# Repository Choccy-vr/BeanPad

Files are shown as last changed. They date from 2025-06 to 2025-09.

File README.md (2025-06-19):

# BeanPad

A modular magnetic macro pad. Use many different modules to make the macro pad of your dreams. Modify the macros.json for a custom keymap.

I built this originally as a buffer for my main project but it has since taken over it. The idea came from other snap-fit modular systems and thought it was cool. I originally was just going to make a hack pad but it quickly grew into this.
I also built this in case my other project doesn't get finished in time for undercity.
## Images

### PCB

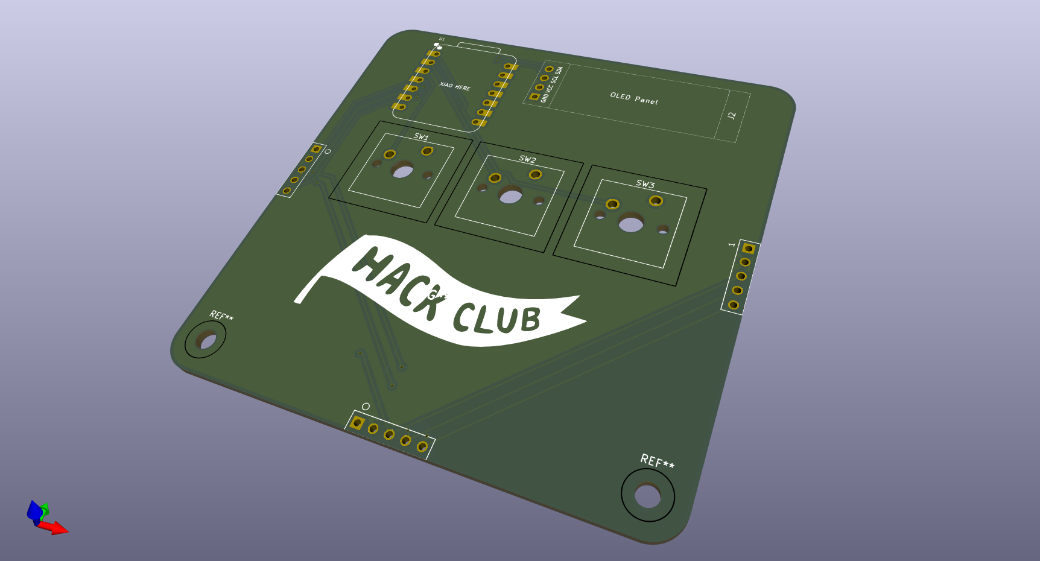
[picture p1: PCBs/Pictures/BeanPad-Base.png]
Screenshot 2025-06-09 151724.png


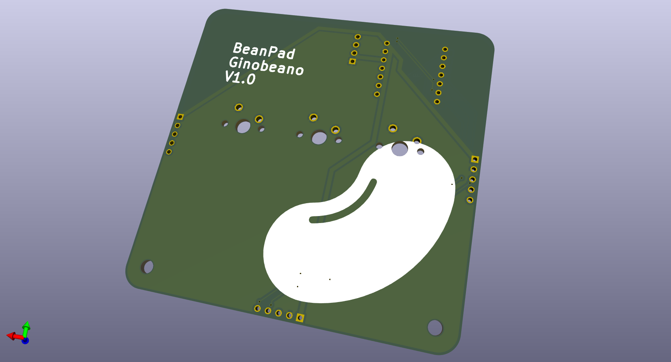
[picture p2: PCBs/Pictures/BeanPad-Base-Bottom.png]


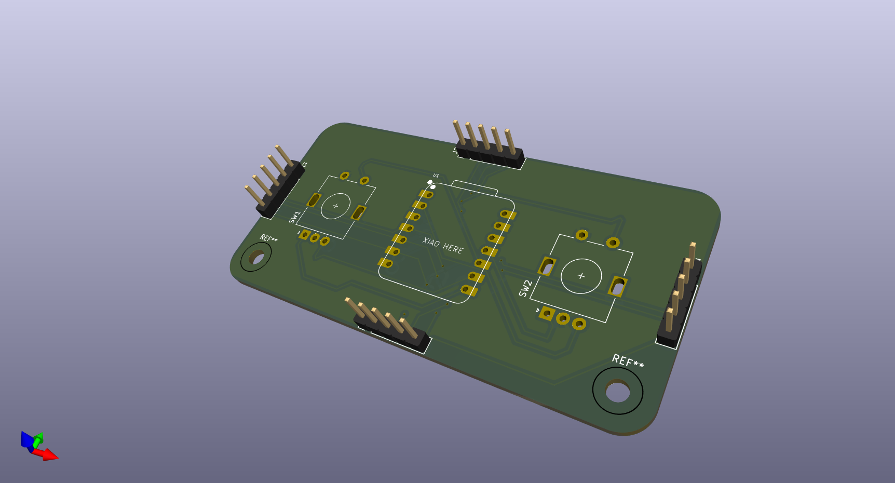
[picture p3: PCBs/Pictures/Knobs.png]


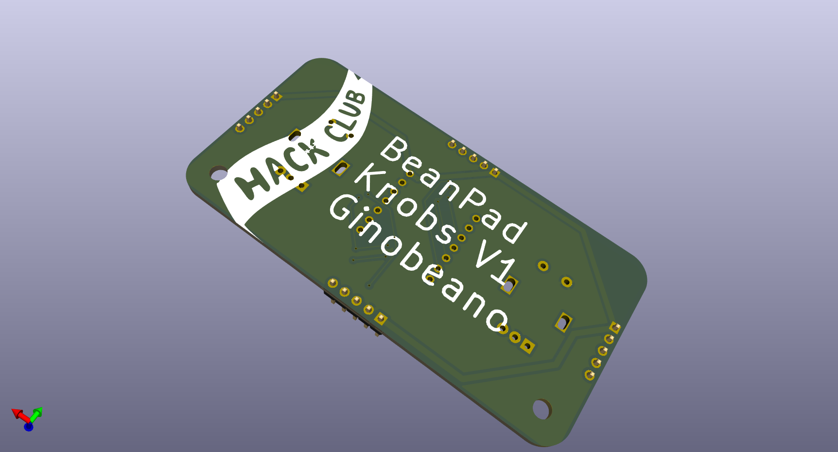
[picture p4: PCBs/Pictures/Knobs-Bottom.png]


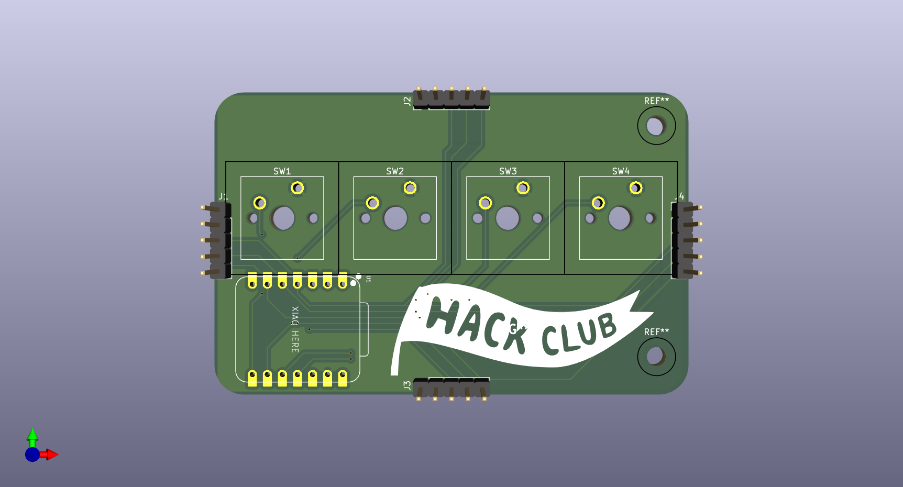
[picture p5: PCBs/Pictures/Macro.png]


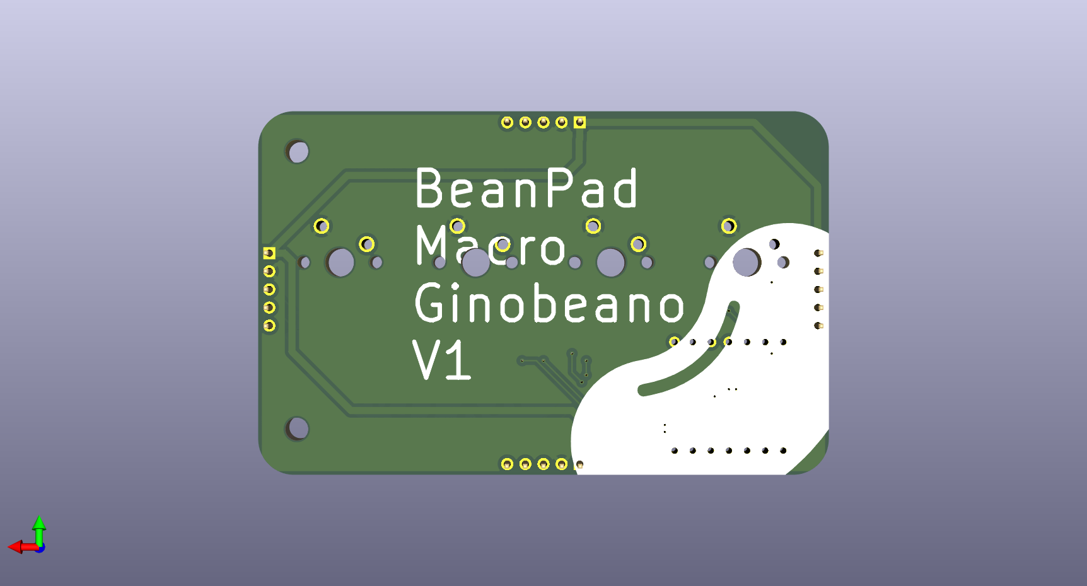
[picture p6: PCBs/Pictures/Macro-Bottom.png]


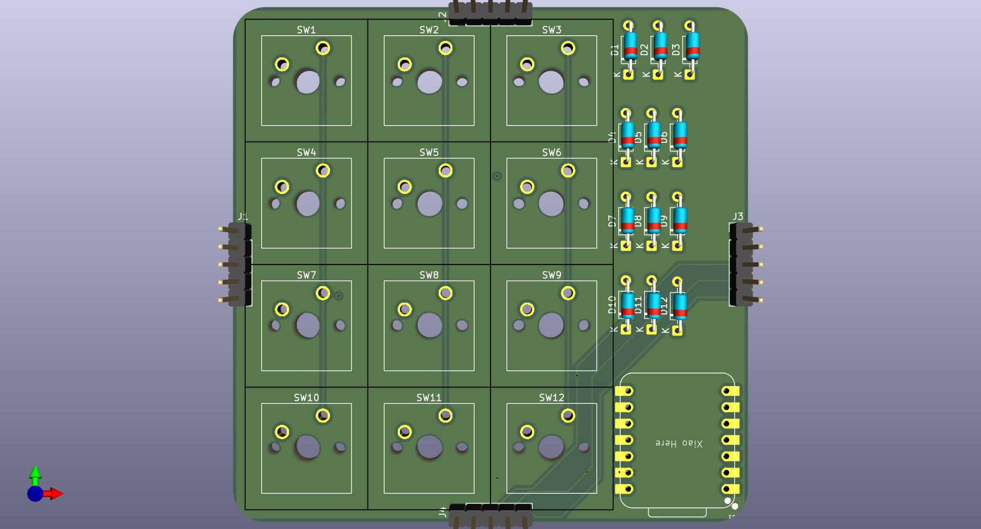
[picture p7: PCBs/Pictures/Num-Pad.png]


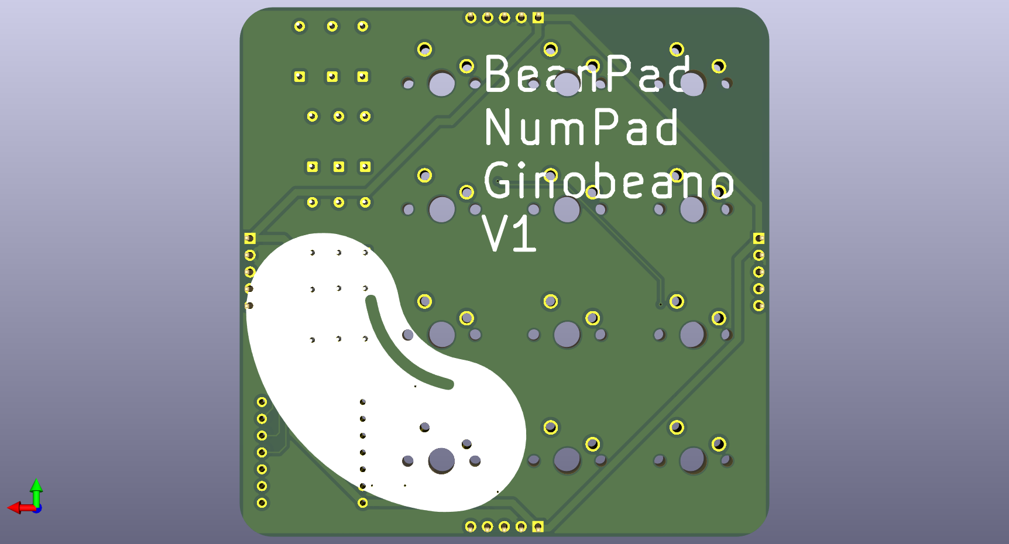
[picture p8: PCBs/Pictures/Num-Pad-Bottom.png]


### Case

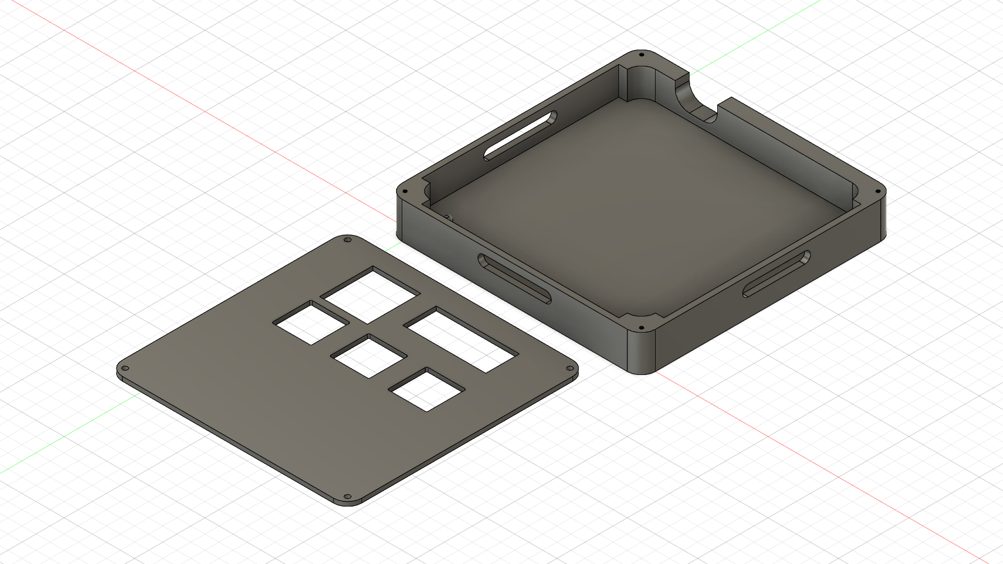
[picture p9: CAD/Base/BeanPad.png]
Screenshot 2025-06-16 152040.png


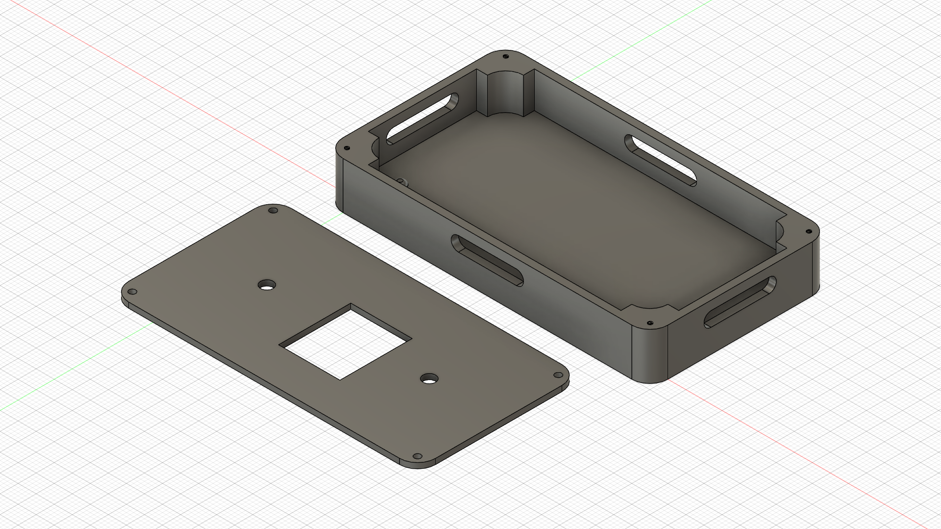
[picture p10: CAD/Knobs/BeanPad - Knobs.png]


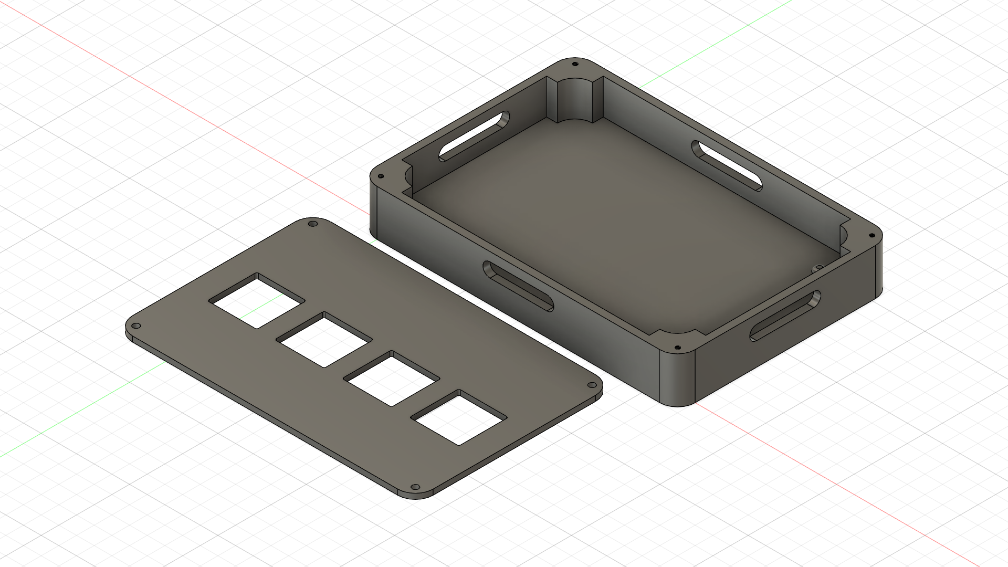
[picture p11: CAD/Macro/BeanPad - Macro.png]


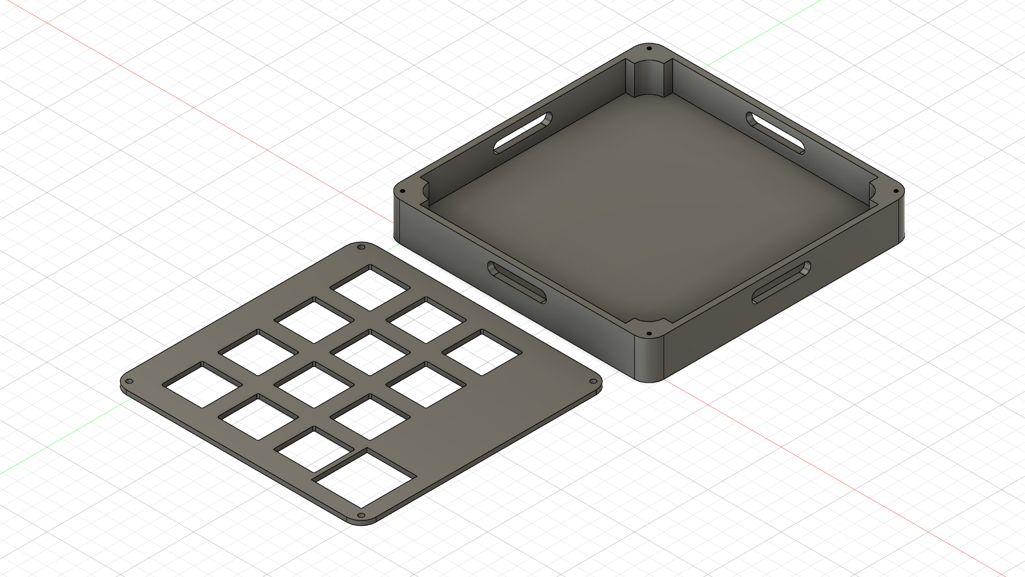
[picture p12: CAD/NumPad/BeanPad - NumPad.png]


### Firmware (Really nothing to see here)

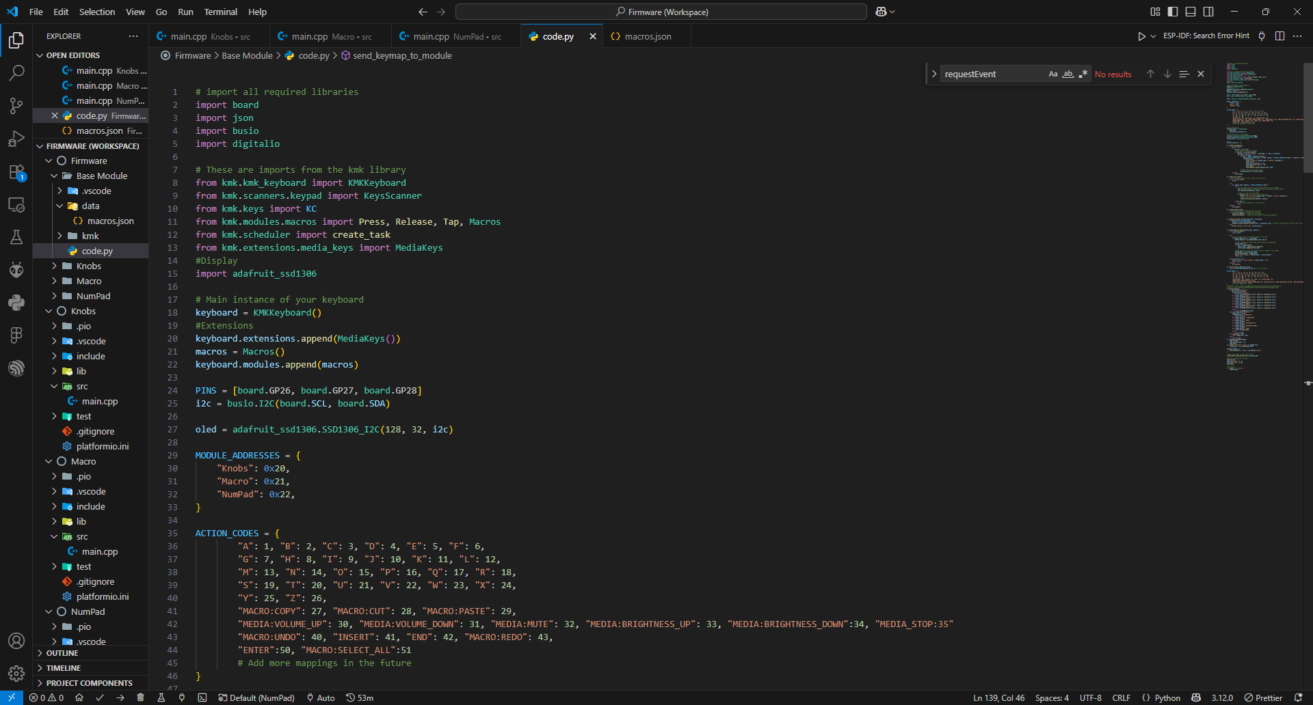
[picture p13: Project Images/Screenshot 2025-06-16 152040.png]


## 
|Item: |Quanity: (If Items come in sets amount of sets)|Source: |Cost:  |Total |
|---|---|---|---|---|
|Screws |1(50pcs) |https://www.aliexpress.us/item/3256802339245383.html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 |$1.50  | |
|Heat Set Inserts  |1(50pcs) |https://www.aliexpress.us/item/3256807466816961.html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 |$2 | |
|Diodes |1(100pcs) |https://www.aliexpress.us/item/2255799955957794.html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 |$1 | |
|Cherry MX Switches|1(30pcs) |https://www.aliexpress.us/item/3256806069646359.html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|$19 | |
|Rotary Encoders |2 |https://www.aliexpress.us/item/3256805010555504.html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 |$3 | |
|KeyCaps |2(24pcs) |https://www.aliexpress.us/item/3256802719703092.html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 |$7 | |
|Pogo Connectors |3(9 pairs) |https://www.aliexpress.us/item/3256806345459324.html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|$21 | |
|Soldering Iron |1 |https://www.aliexpress.us/item/3256806823950124.html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  |$8 | |
|XIAO Rp2040s |2 (6pcs) |https://www.seeedstudio.com/Seeed-Studio-XIAO-RP2040-3PCS-p-5942.html |$27 | |
|PCBs |4 |https://www.pcbway.com/ |$47.84 | |
|Total | | | |$148.23 (Includes Shipping and Taxes)|

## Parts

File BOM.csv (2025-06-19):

Item: | Quanity: (If Items come in sets amount of sets) | Source: | Cost: | Total
Screws | 1(50pcs) | https://www.aliexpress.us/item/3256802339245383.html?mp=1 | $1.50
Heat Set Inserts | 1(50pcs) | https://www.aliexpress.us/item/3256807466816961.html?mp=1 | $2
Diodes | 1(100pcs) | https://www.aliexpress.us/item/2255799955957794.html?mp=1 | $1
Cherry MX Switches | 1(30pcs) | https://www.aliexpress.us/item/3256806069646359.html?mp=1 | $19
Rotary Encoders | 2 | https://www.aliexpress.us/item/3256805010555504.html?mp=1 | $3
KeyCaps | 2(24pcs) | https://www.aliexpress.us/item/3256802719703092.html?mp=1 | $7
Pogo Connectors | 3(9 pairs) | https://www.aliexpress.us/item/3256806345459324.html?mp=1 | $21
Soldering Iron | 1 | https://www.aliexpress.us/item/3256806823950124.html?mp=1 | $8
XIAO Rp2040s | 2 (6pcs) | https://www.seeedstudio.com/Seeed-Studio-XIAO-RP2040-3PCS-p-5942.html | $27
PCBs | 4 | https://www.pcbway.com/ | $47.84
Total |  |  |  | $148.23 (Includes Shipping and Taxes)

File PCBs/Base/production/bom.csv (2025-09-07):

Designator | Footprint | Quantity | Value | LCSC Part #
J1, J3, J5 | male_only_connector_5pin_Version3 | 3 | Male_Pogo_Connector_01x05
J2 | SSD1306-0.91-OLED-4pin-128x32 | 1 | Display
SW1, SW2, SW3 | SW_Cherry_MX_1.00u_PCB | 3 | SW_Push
U1 | XIAO-RP2040-DIP | 1 | XIAO-RP2040-DIP

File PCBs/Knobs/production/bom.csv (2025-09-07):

Designator | Footprint | Quantity | Value | LCSC Part #
J1, J2, J3, J4 | PinHeader_1x05_P2.54mm_Vertical | 4 | Male_Pogo_Connector_01x05
SW1, SW2 | RotaryEncoder_Alps_EC11E-Switch_Vertical_H20mm | 2 | RotaryEncoder_Switch
U1 | XIAO-RP2040-DIP | 1 | XIAO-RP2040-DIP

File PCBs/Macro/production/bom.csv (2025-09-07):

Designator | Footprint | Quantity | Value | LCSC Part #
J1, J2, J3, J4 | PinHeader_1x05_P2.54mm_Vertical | 4 | Male_Pogo_Connector_01x05
SW1, SW2, SW3, SW4 | SW_Cherry_MX_1.00u_PCB | 4 | SW_Push
U1 | XIAO-RP2040-DIP | 1 | XIAO-RP2040-DIP

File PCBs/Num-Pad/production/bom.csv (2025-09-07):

Designator | Footprint | Quantity | Value | LCSC Part #
D1, D10, D11, D12, D2, D3, D4, D5, D6, D7, D8, D9 | D_DO-35_SOD27_P7.62mm_Horizontal | 12 | D_Small
J1, J2, J3, J4 | PinHeader_1x05_P2.54mm_Vertical | 4 | Male_Pogo_Connector_01x05
SW1, SW10, SW11, SW12, SW2, SW3, SW4, SW5, SW6, SW7, SW8, SW9 | SW_Cherry_MX_1.00u_PCB | 12 | SW_Push_45deg
U1 | XIAO-RP2040-DIP | 1 | XIAO-RP2040-DIP

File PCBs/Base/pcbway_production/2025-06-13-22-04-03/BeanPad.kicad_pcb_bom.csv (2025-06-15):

Designator | Quantity | Value | Footprint | Package | MPN | DNP | Mount_Type | Description
J1, J3, J5 | 3 | Male_Pogo_Connector_01x05 | male_only_connector_5pin_Version3 |  |  |  | tht
J2 | 1 | Display | SSD1306-0.91-OLED-4pin-128x32 |  |  |  | tht | Generic connector, single row, 01x04, script generated
SW1, SW2, SW3 | 3 | SW_Push | SW_Cherry_MX_1.00u_PCB |  |  |  | tht | Push button switch, generic, two pins
U1 | 1 | XIAO-RP2040-DIP | XIAO-RP2040-DIP |  |  |  | smt

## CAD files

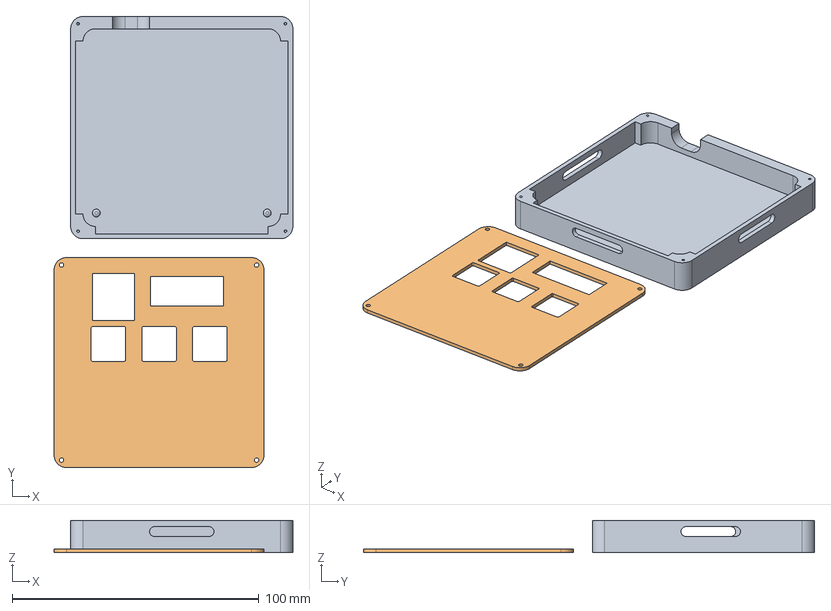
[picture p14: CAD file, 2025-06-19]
CAD/Base/BeanPad.step
96.7 x 182.7 x 13.0 mm

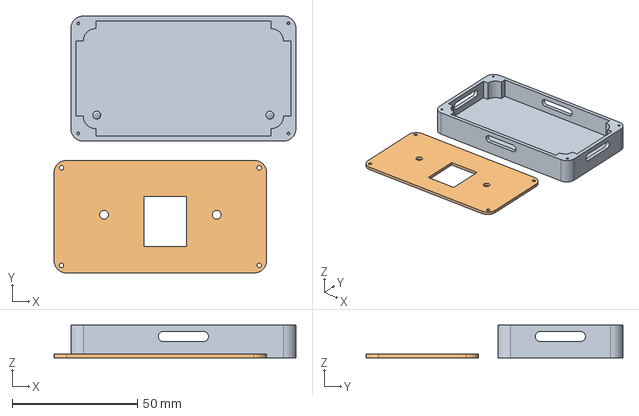
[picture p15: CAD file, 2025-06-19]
CAD/Knobs/BeanPad - Knobs.step
96.7 x 102.7 x 13.0 mm

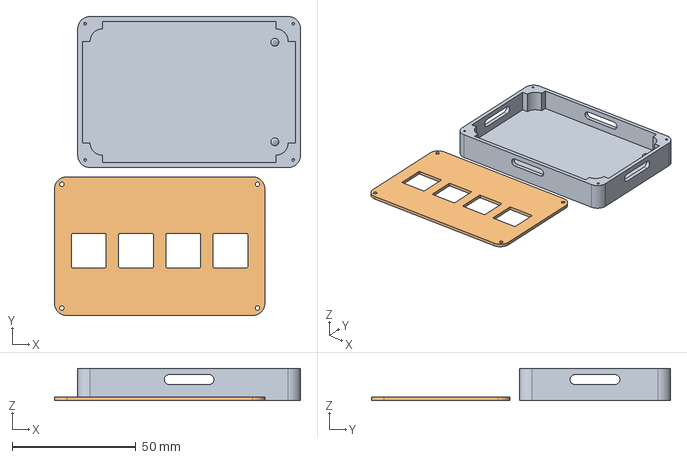
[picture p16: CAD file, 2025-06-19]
CAD/Macro/BeanPad - Macro.step
99.4 x 120.7 x 13.0 mm

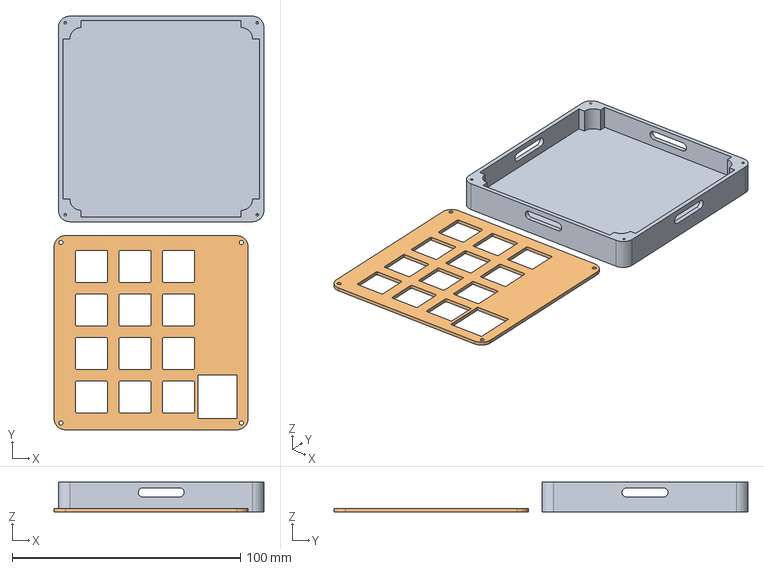
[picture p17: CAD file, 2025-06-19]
CAD/NumPad/BeanPad - NumPad.step
91.9 x 181.1 x 13.0 mm

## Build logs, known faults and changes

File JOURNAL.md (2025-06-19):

---

title: "BeanPad"
author: "Ginobeano"
description: "A modular smart macropad"
created_at: "2025-06-09"

---

# Total Time Spent: 37h

# June 09: Started PCB & Project

- Decided on using an RP2040 might change it down the road to add buletooth would have to do more research on it though.

- I finished the first version of the main module schematic

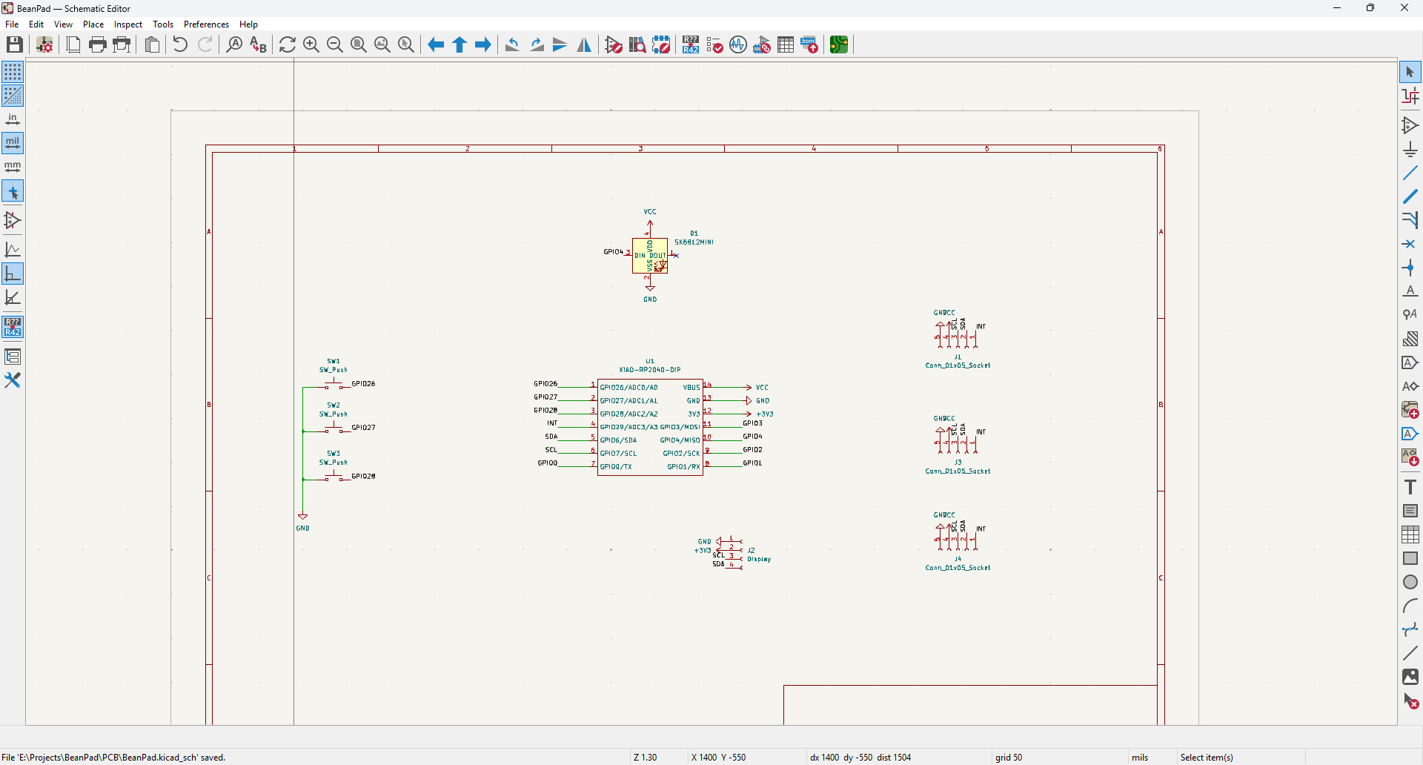
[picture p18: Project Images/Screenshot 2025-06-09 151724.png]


**Time Spent: 3h**

- I finished the PCB took a pretty long time relaxing though.
  
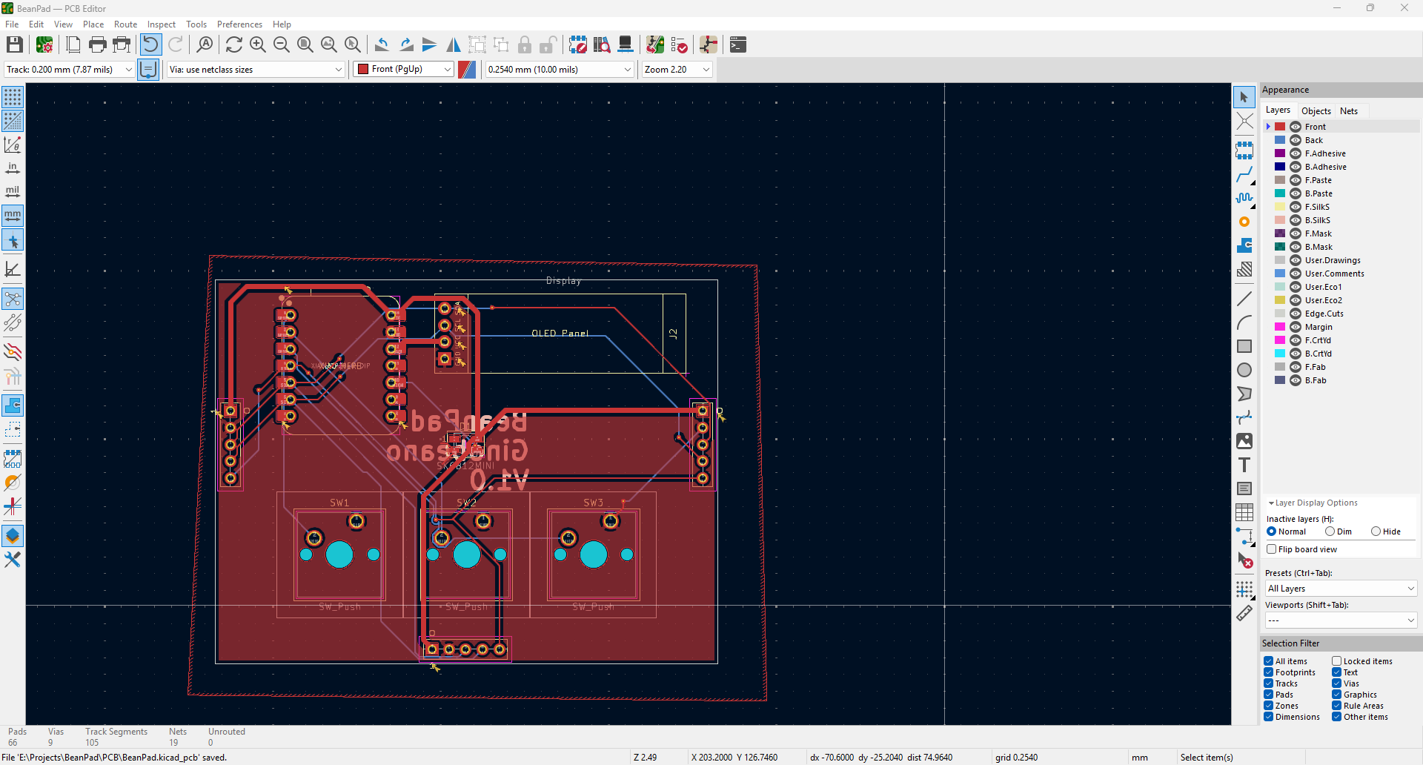
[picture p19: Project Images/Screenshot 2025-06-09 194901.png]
Screenshot 2025-06-09 194901.png
  
  
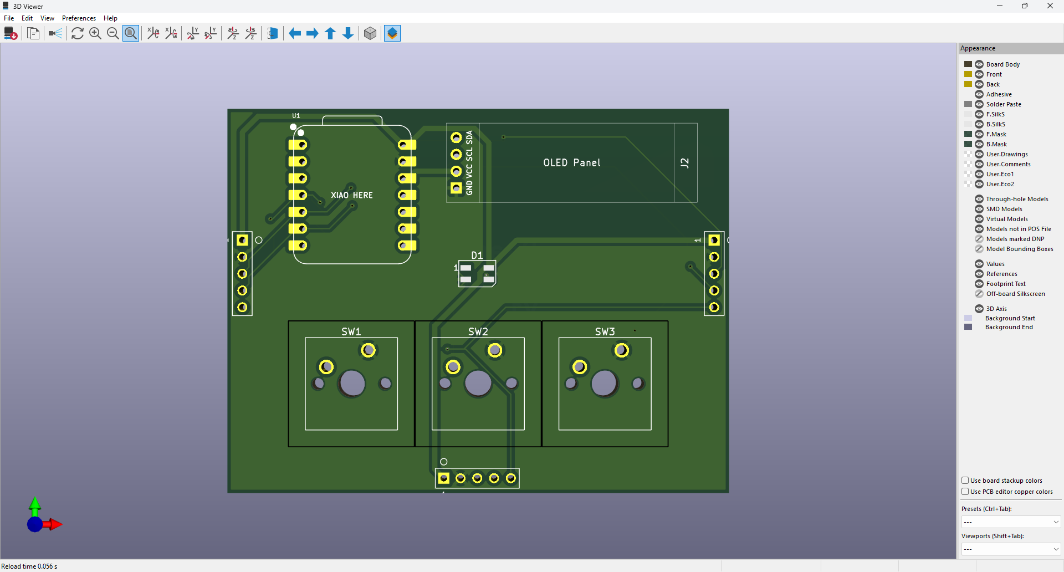
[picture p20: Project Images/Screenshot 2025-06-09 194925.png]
Screenshot 2025-06-09 194925.png
  

**Time Spent: 3h**

##### **Total Time Spent: 6h**

# June 10th: Case & PCB

- For some reason I didn't think to put mounting holes on the PCB so I added those

- Started up Fusion 360 and time to start on the case.

**Total Time Spent: 5h**

# June 11th: Case

- I finished a early prototype of the case which is good but ...

- I need to wait till after I get the connectors to do final measurements had to kinda guess for right now

- I got done I would call V0.1 so I would count it as a success 

- This concludes hardware for the main module on to software

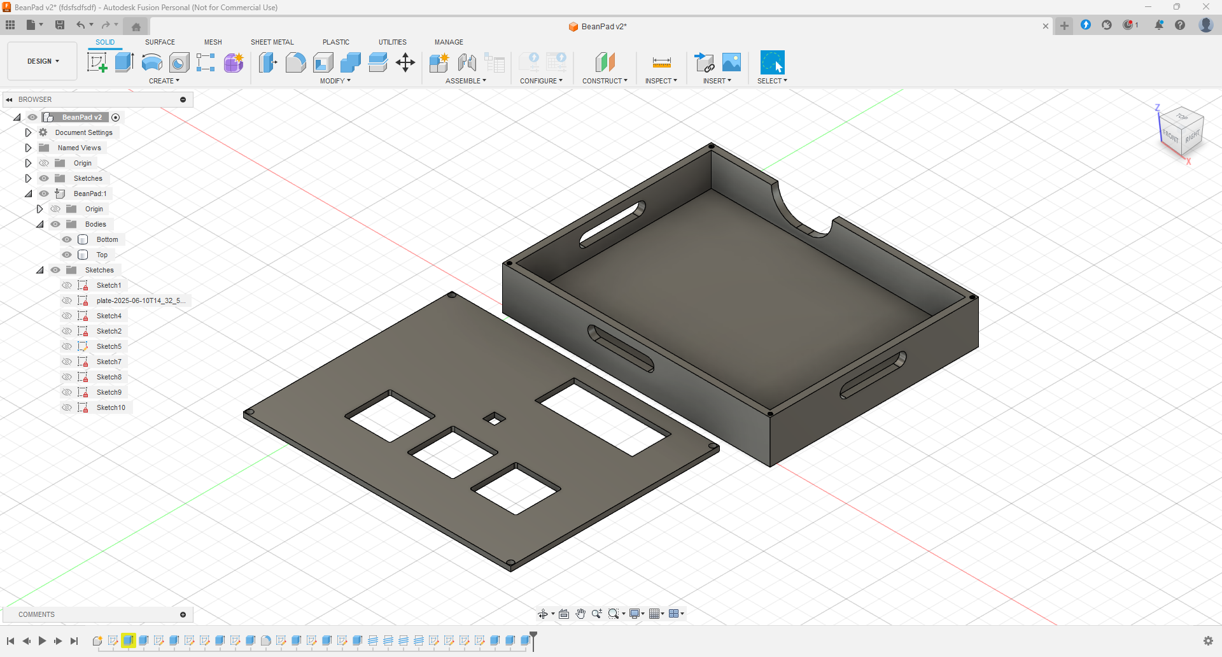
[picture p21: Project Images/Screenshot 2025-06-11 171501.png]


**Total Time Spent: 3h**

# June 12th & 13th: Firmware

- I forgot to journal yesterday but I just researched the diffrent firmware options

- I landed on kmk and circuit python might have to change it though.

**Time Spent: 1.5h**

### June 13th:

- Started working on coding the firmware

- I am abosuloutley loving kmk; circuit python not so much

**Time Spent: 2.5h**

**Total Time spent 4h**

# June 14th: Modules!

- First I changed the Base Module PCB to rearrange and fix some things

- I then Finished the Base Module CAD design and edited it to account for the new PCB

- Forgot to mention that I researched and planned all the modules. Right now there will be 4 module:
  
  - Base Module (REQUIRED)
  
  - Knobs
  
  - Macro
  
  - Num-Pad

- I then finished the Knobs Module

- Overall great work day.

**Total TIme spent: 6.5h**

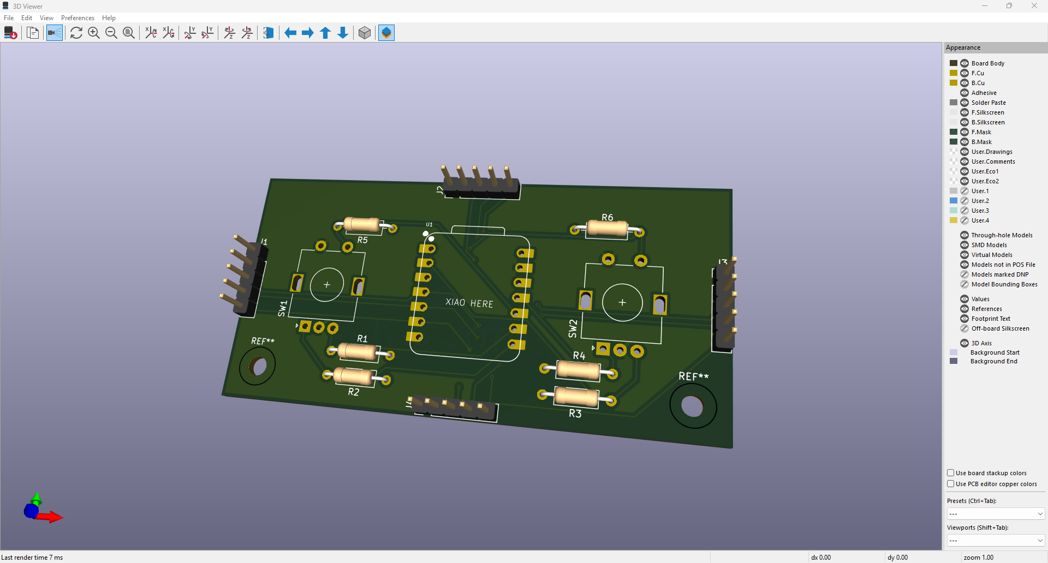
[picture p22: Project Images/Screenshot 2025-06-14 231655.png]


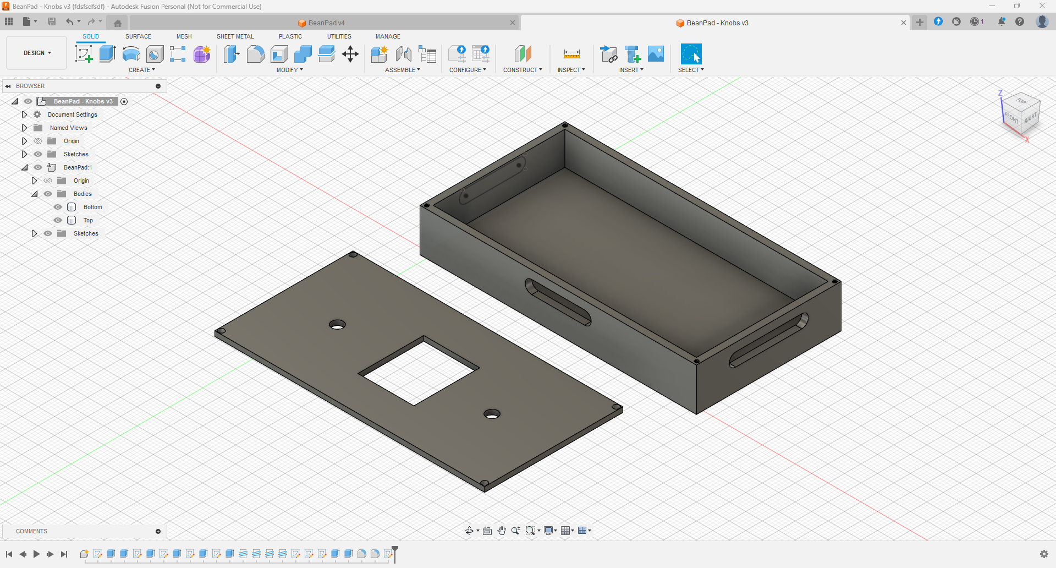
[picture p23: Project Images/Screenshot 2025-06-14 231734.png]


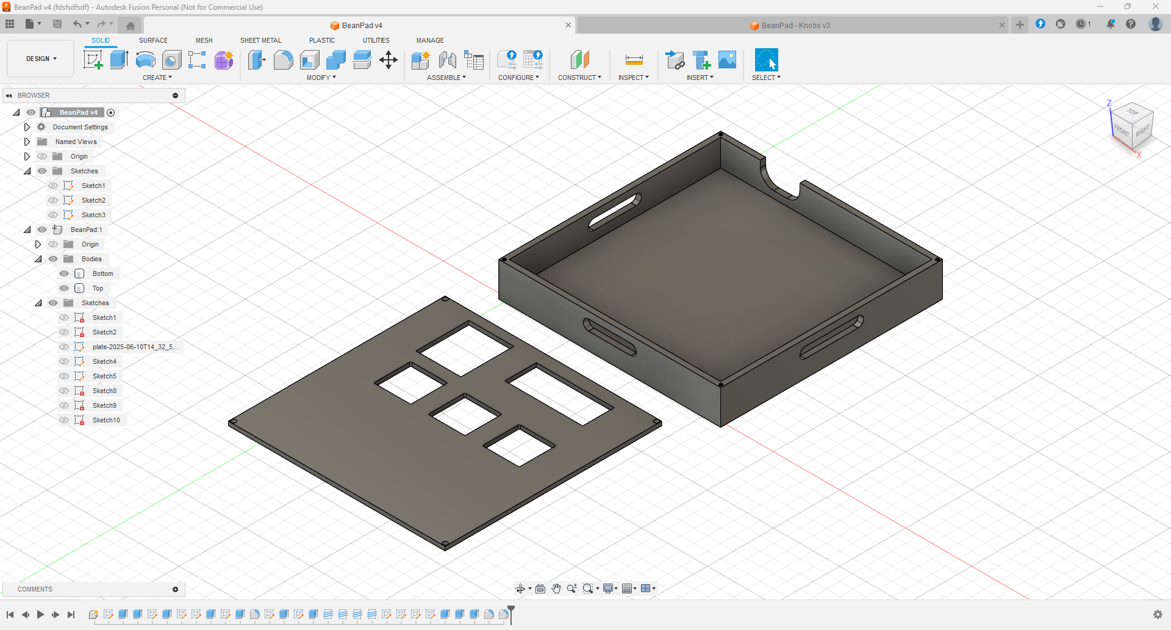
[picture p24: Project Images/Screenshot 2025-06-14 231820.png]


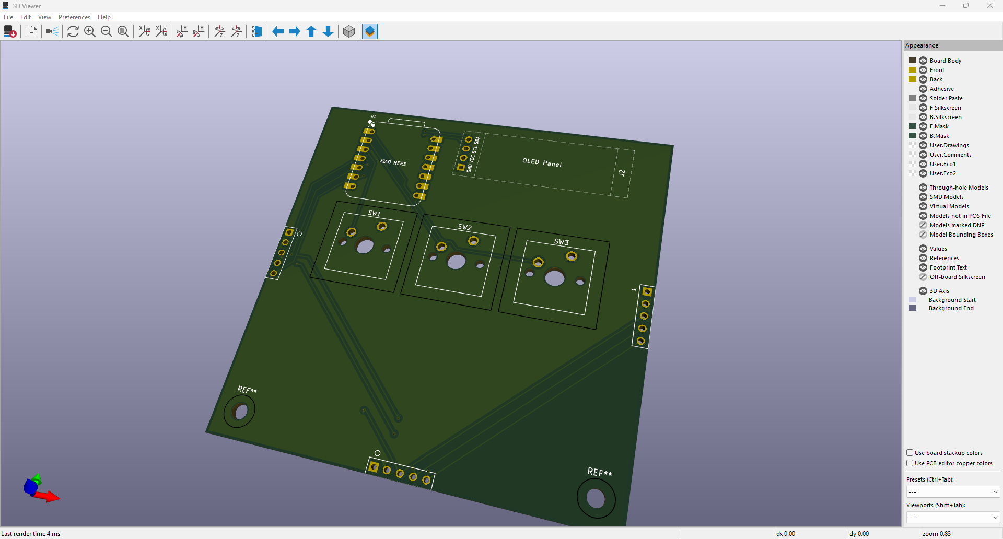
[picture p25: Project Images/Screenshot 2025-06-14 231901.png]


# June 15th: Almost Completed Firmware

- I was getting a little bored with designing PCB and cases so I decided to work on the firmware

- The Base Module is written in Circuit Python while the rest are written in Arduino (C++)

- The Base Module handles the modules and its own buttons and screen while the other modules just handle themselves and send their action.

- This part was pretty easy for me because coding is my specialty

- I almost completed all of the Firmware except the Numpad Module

**Total Time Spent: 6h**

# June 16th: Finish

- **The BeanPad is offically done!!!!!!!**

- That is right I have sumbited BeanPad and waiting for it to be approved 

- Lets get pass what I did today it was alot

- I signed up for Summer of Making which is pretty cool

- I installed all of the tracking stuff still having problems with it though.

- I got rid of the resistors on the Knobs Module because I don't need them ty @StrawberryPuding and @luteron6 on Slack

- I finished the firmware for the numpad and as a result done all of the firmware

- I finished all case designing



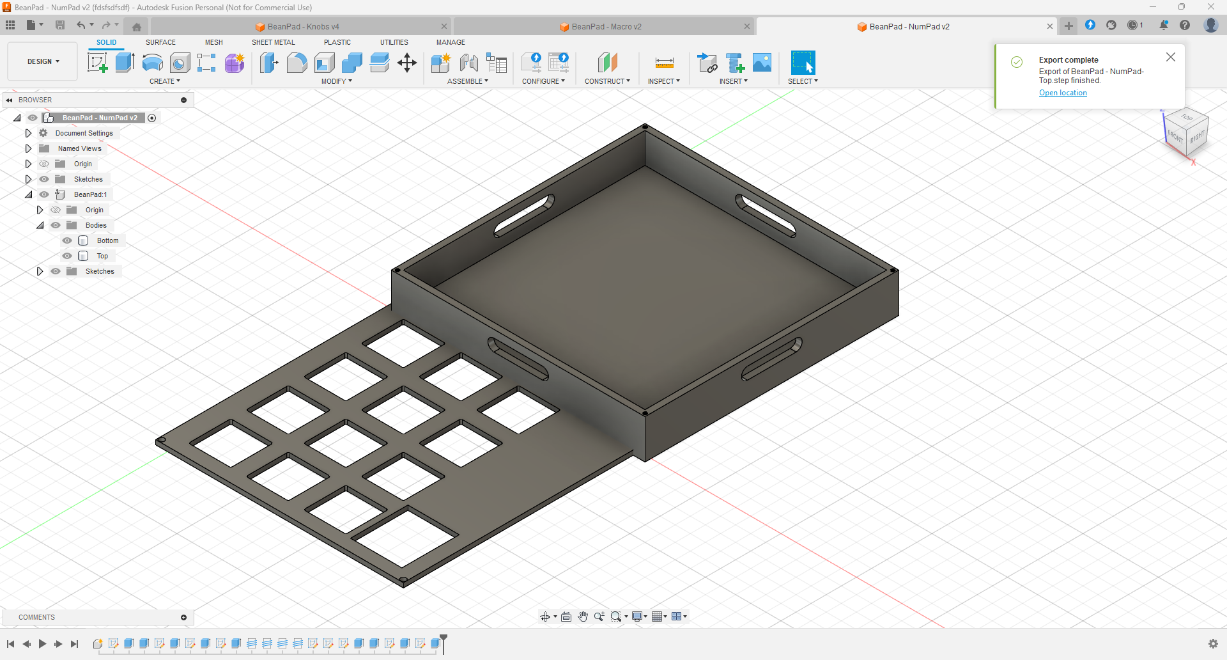
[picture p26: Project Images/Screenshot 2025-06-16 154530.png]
Screenshot 2025-06-16 152040.png


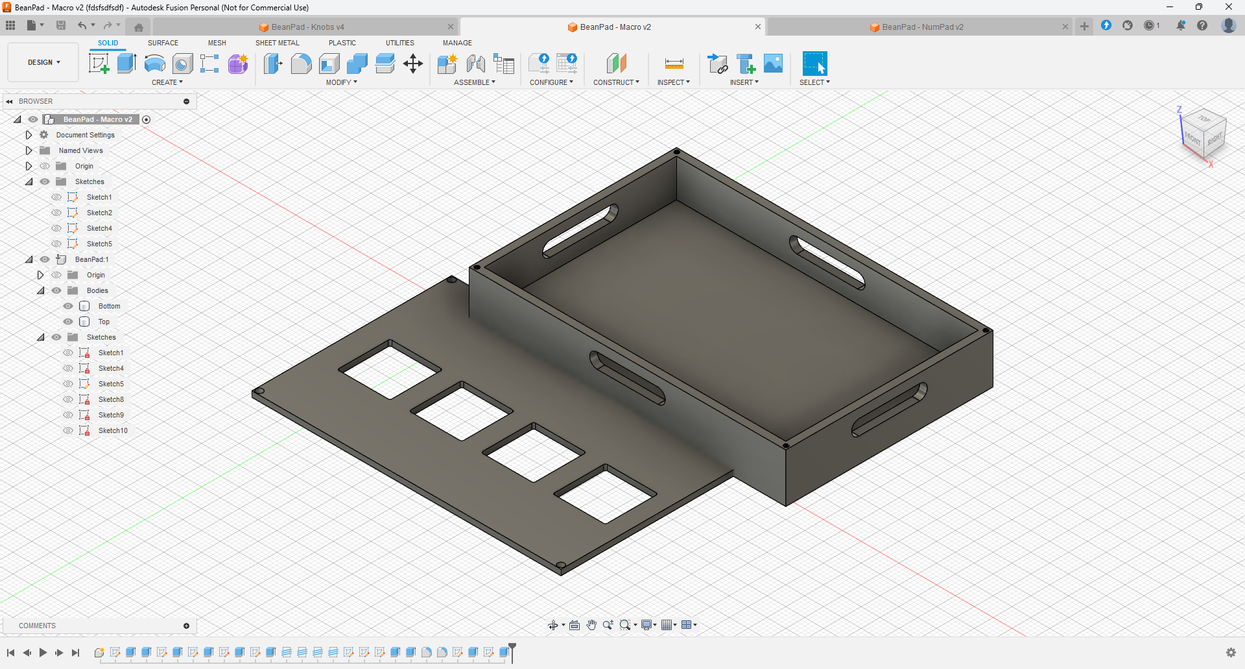
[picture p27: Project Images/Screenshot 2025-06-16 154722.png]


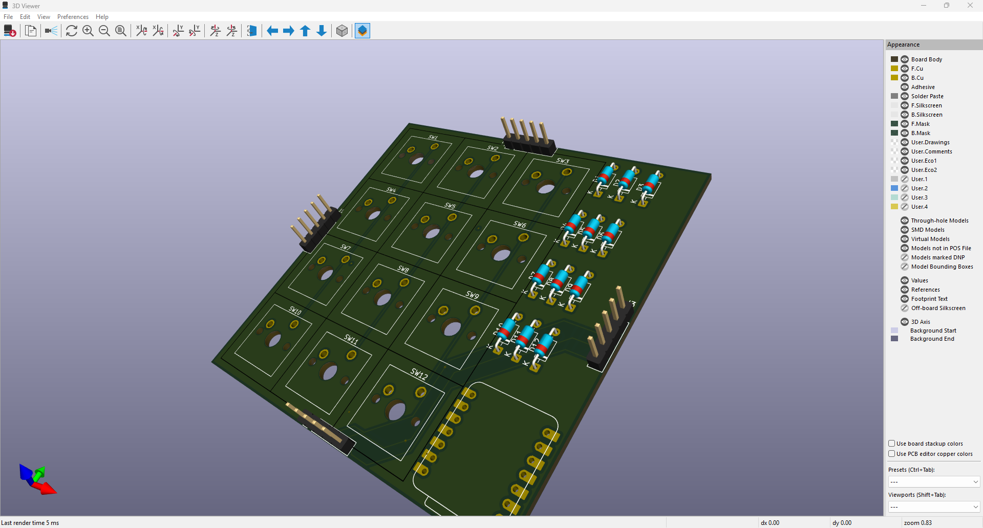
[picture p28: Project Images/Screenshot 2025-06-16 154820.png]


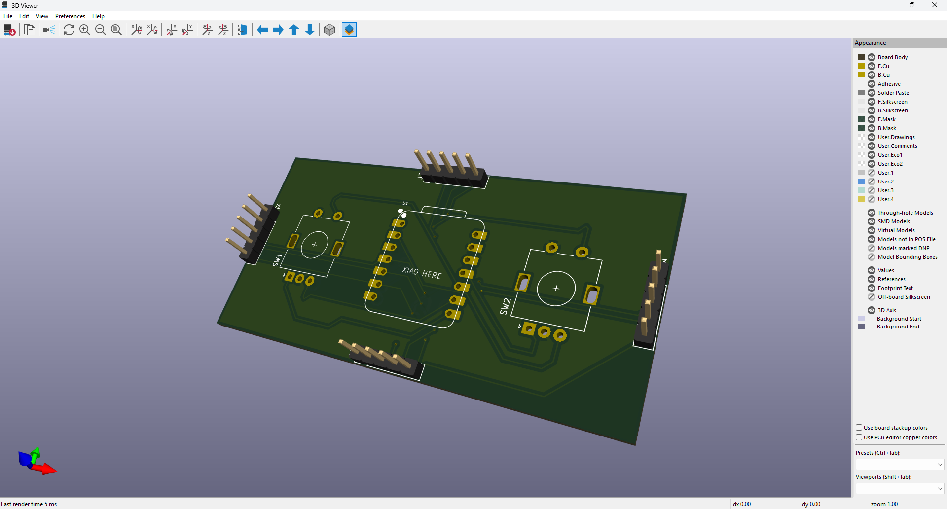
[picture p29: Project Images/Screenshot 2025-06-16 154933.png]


**Total Time Spent: 4.5h**

# June 19th: Modify

- I had to fix up to Cad Models it looks a lot better now hopefuly the pogo pin connectors still fit. They should fingers crossed.

- I was also missing the Quanity and Price from my BOM so gotta fix that.

**Total Time Spent: 2h**

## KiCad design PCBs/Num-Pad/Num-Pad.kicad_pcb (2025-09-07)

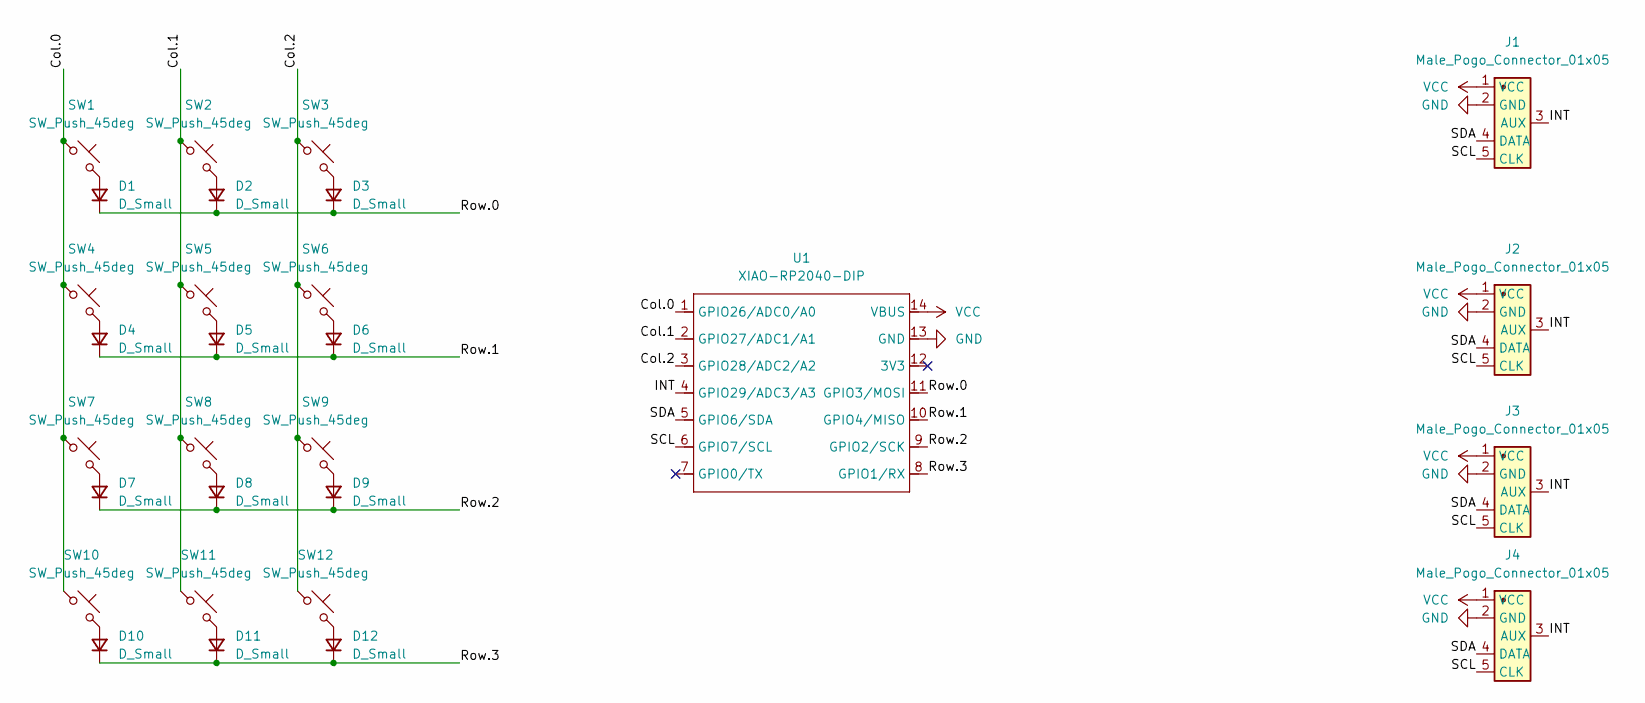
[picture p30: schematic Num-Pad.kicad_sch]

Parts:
D1, D2, D3, D4, D5, D6, D7, D8, D9, D10, D11, D12: D_Small; D_DO-35_SOD27_P7.62mm_Horizontal
J1, J2, J3, J4: Male_Pogo_Connector_01x05; PinHeader_1x05_P2.54mm_Vertical
SW1, SW2, SW3, SW4, SW5, SW6, SW7, SW8, SW9, SW10, SW11, SW12: SW_Push_45deg; SW_Cherry_MX_1.00u_PCB
U1: XIAO-RP2040-DIP

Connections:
/Col.0: SW1.1, SW4.1, SW7.1, SW10.1, U1.1 (GPIO26/ADC0/A0)
/Col.1: SW2.1, SW5.1, SW8.1, SW11.1, U1.2 (GPIO27/ADC1/A1)
/Col.2: SW3.1, SW6.1, SW9.1, SW12.1, U1.3 (GPIO28/ADC2/A2)
/INT: J1.3 (AUX), J2.3 (AUX), J3.3 (AUX), J4.3 (AUX), U1.4 (GPIO29/ADC3/A3)
/Row.0: D1.1 (K), D2.1 (K), D3.1 (K), U1.11 (GPIO3/MOSI)
/Row.1: D4.1 (K), D5.1 (K), D6.1 (K), U1.10 (GPIO4/MISO)
/Row.2: D7.1 (K), D8.1 (K), D9.1 (K), U1.9 (GPIO2/SCK)
/Row.3: D10.1 (K), D11.1 (K), D12.1 (K), U1.8 (GPIO1/RX)
/SCL: J1.5 (CLK), J2.5 (CLK), J3.5 (CLK), J4.5 (CLK), U1.6 (GPIO7/SCL)
/SDA: J1.4 (DATA), J2.4 (DATA), J3.4 (DATA), J4.4 (DATA), U1.5 (GPIO6/SDA)
GND: J1.2 (GND), J2.2 (GND), J3.2 (GND), J4.2 (GND), U1.13 (GND)
unnamed: D1.2 (A), SW1.2
unnamed: D2.2 (A), SW2.2
unnamed: D3.2 (A), SW3.2
unnamed: D4.2 (A), SW4.2
unnamed: D5.2 (A), SW5.2
unnamed: D6.2 (A), SW6.2
unnamed: D7.2 (A), SW7.2
unnamed: D8.2 (A), SW8.2
unnamed: D9.2 (A), SW9.2
unnamed: D10.2 (A), SW10.2
unnamed: D11.2 (A), SW11.2
unnamed: D12.2 (A), SW12.2
VCC: J1.1 (VCC), J2.1 (VCC), J3.1 (VCC), J4.1 (VCC), U1.14 (VBUS)

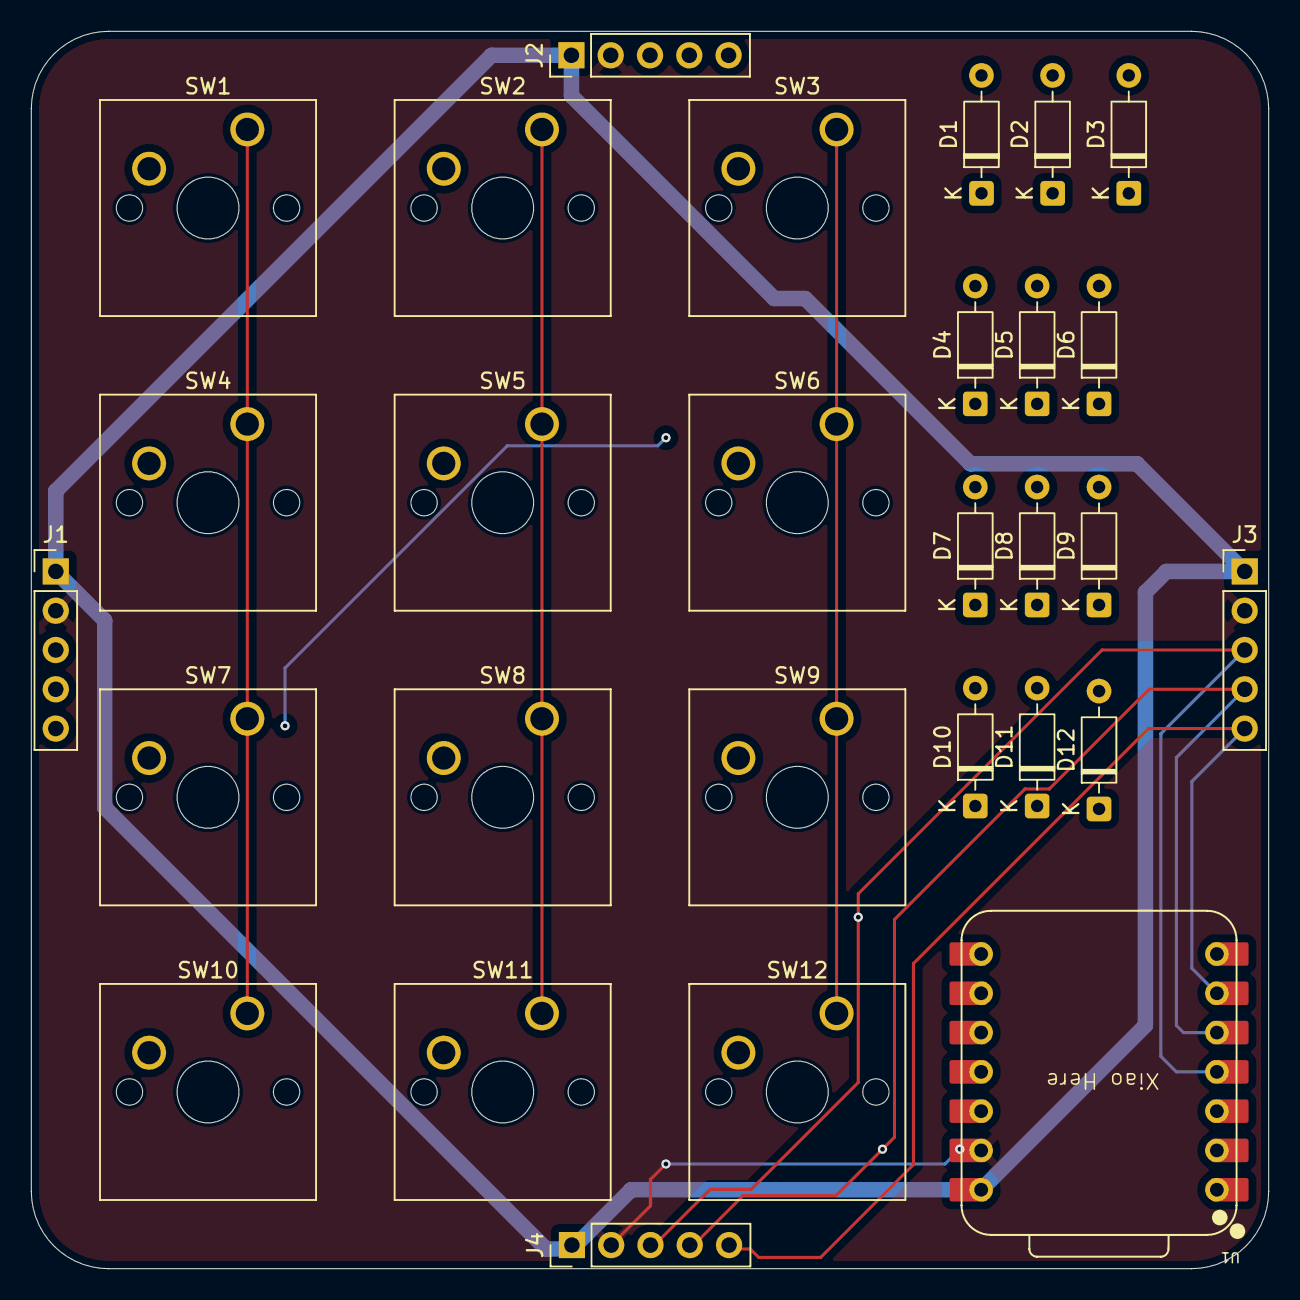
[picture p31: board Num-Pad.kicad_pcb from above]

Board: 4 copper layers, 80.0 x 80.0 mm, 29 parts (0 on the bottom side), 24 nets.

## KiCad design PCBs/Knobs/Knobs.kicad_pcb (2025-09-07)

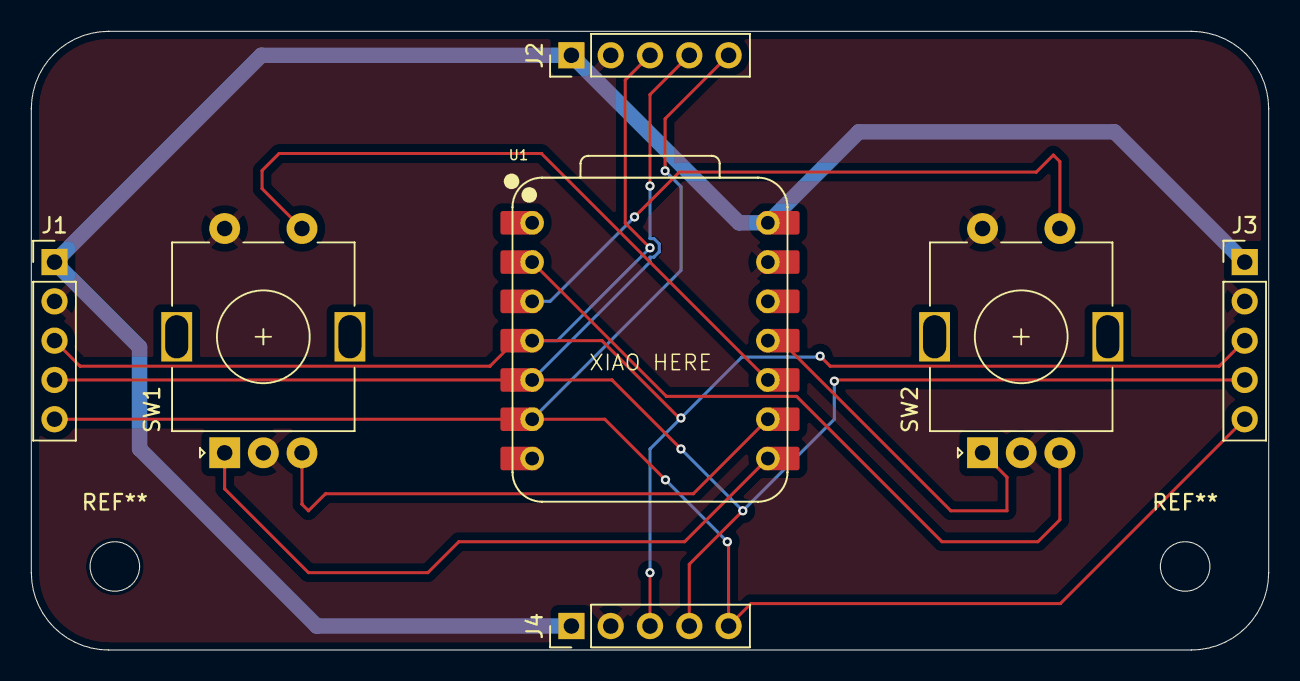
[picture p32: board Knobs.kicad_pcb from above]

Board: 2 copper layers, 80.0 x 40.0 mm, 7 parts (0 on the bottom side), 11 nets.

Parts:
J1, J2, J3, J4: Male_Pogo_Connector_01x05; PinHeader_1x05_P2.54mm_Vertical
SW1, SW2: RotaryEncoder_Switch; RotaryEncoder_Alps_EC11E-Switch_Vertical_H20mm
U1: XIAO-RP2040-DIP

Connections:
/GPIO1: SW1.A, U1.8 (GPIO1/RX)
/GPIO2: SW1.B, U1.9 (GPIO2/SCK)
/GPIO3: SW2.A, U1.11 (GPIO3/MOSI)
/GPIO4: SW1.S1, U1.10 (GPIO4/MISO)
/GPIO27: SW2.B, U1.2 (GPIO27/ADC1/A1)
/GPIO28: SW2.S1, U1.3 (GPIO28/ADC2/A2)
/INT: J1.3 (AUX), J2.3 (AUX), J3.3 (AUX), J4.3 (AUX), U1.4 (GPIO29/ADC3/A3)
/SCL: J1.5 (CLK), J2.5 (CLK), J3.5 (CLK), J4.5 (CLK), U1.6 (GPIO7/SCL)
/SDA: J1.4 (DATA), J2.4 (DATA), J3.4 (DATA), J4.4 (DATA), U1.5 (GPIO6/SDA)
GND: J1.2 (GND), J2.2 (GND), J3.2 (GND), J4.2 (GND), SW1.C, SW1.S2, SW2.C, SW2.S2, U1.13 (GND)
VCC: J1.1 (VCC), J2.1 (VCC), J3.1 (VCC), J4.1 (VCC), U1.14 (VBUS)

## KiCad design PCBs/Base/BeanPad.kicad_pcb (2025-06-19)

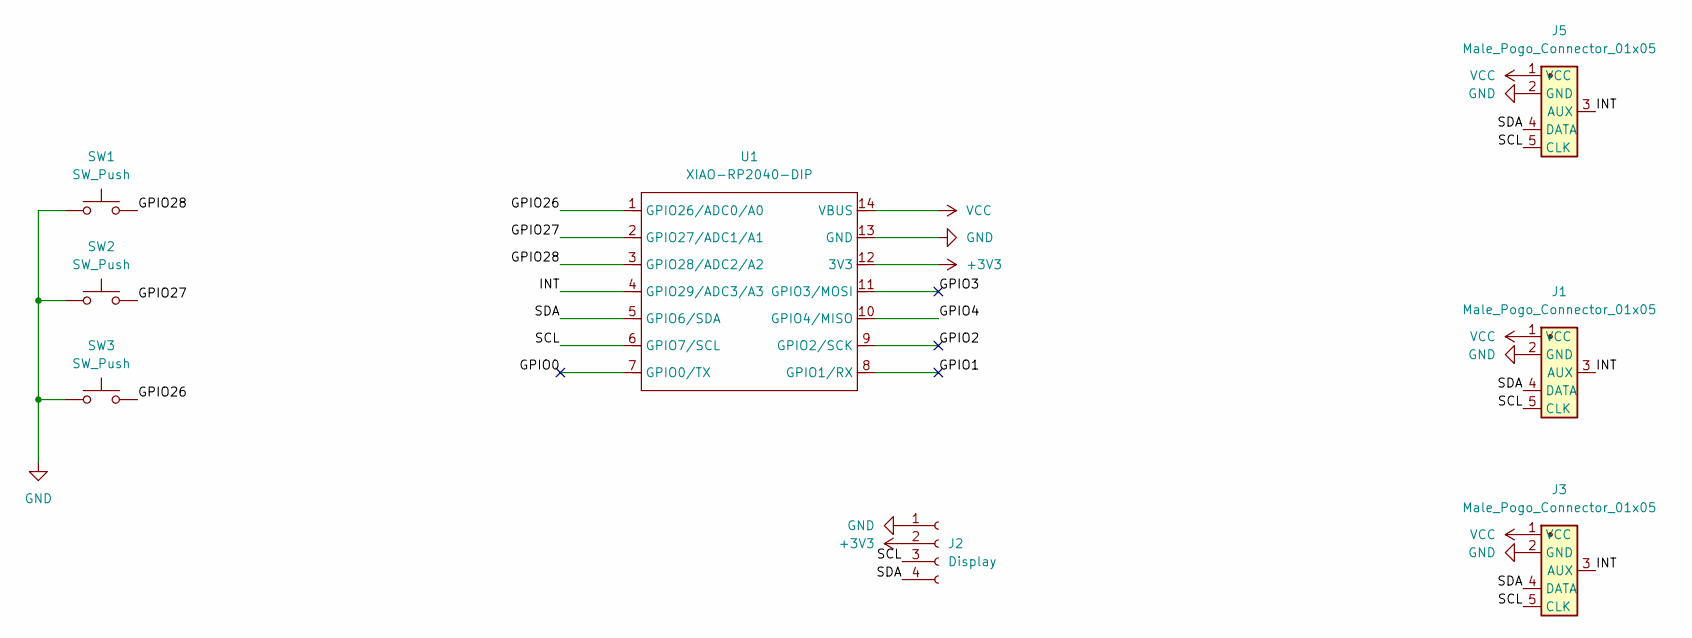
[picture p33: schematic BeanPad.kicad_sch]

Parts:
J1, J3, J5: Male_Pogo_Connector_01x05; PinHeader_1x05_P2.54mm_Vertical
J2: Display; SSD1306-0.91-OLED-4pin-128x32
SW1, SW2, SW3: SW_Push; SW_Cherry_MX_1.00u_PCB
U1: XIAO-RP2040-DIP

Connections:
+3V3: J2.2, U1.12 (3V3)
/GPIO0: U1.7 (GPIO0/TX)
/GPIO0_1: U1.7 (GPIO0/TX)
/GPIO1: U1.8 (GPIO1/RX)
/GPIO1_1: U1.8 (GPIO1/RX)
/GPIO2: U1.9 (GPIO2/SCK)
/GPIO2_1: U1.9 (GPIO2/SCK)
/GPIO3: U1.11 (GPIO3/MOSI)
/GPIO3_1: U1.11 (GPIO3/MOSI)
/GPIO4: U1.10 (GPIO4/MISO)
/GPIO26: SW3.2, U1.1 (GPIO26/ADC0/A0)
/GPIO27: SW2.2, U1.2 (GPIO27/ADC1/A1)
/GPIO28: SW1.2, U1.3 (GPIO28/ADC2/A2)
/INT: J1.3 (AUX), J3.3 (AUX), J5.3 (AUX), U1.4 (GPIO29/ADC3/A3)
/SCL: J1.5 (CLK), J2.3, J3.5 (CLK), J5.5 (CLK), U1.6 (GPIO7/SCL)
/SDA: J1.4 (DATA), J2.4, J3.4 (DATA), J5.4 (DATA), U1.5 (GPIO6/SDA)
GND: J1.2 (GND), J2.1, J3.2 (GND), J5.2 (GND), SW1.1, SW2.1, SW3.1, U1.13 (GND)
VCC: J1.1 (VCC), J3.1 (VCC), J5.1 (VCC), U1.14 (VBUS)

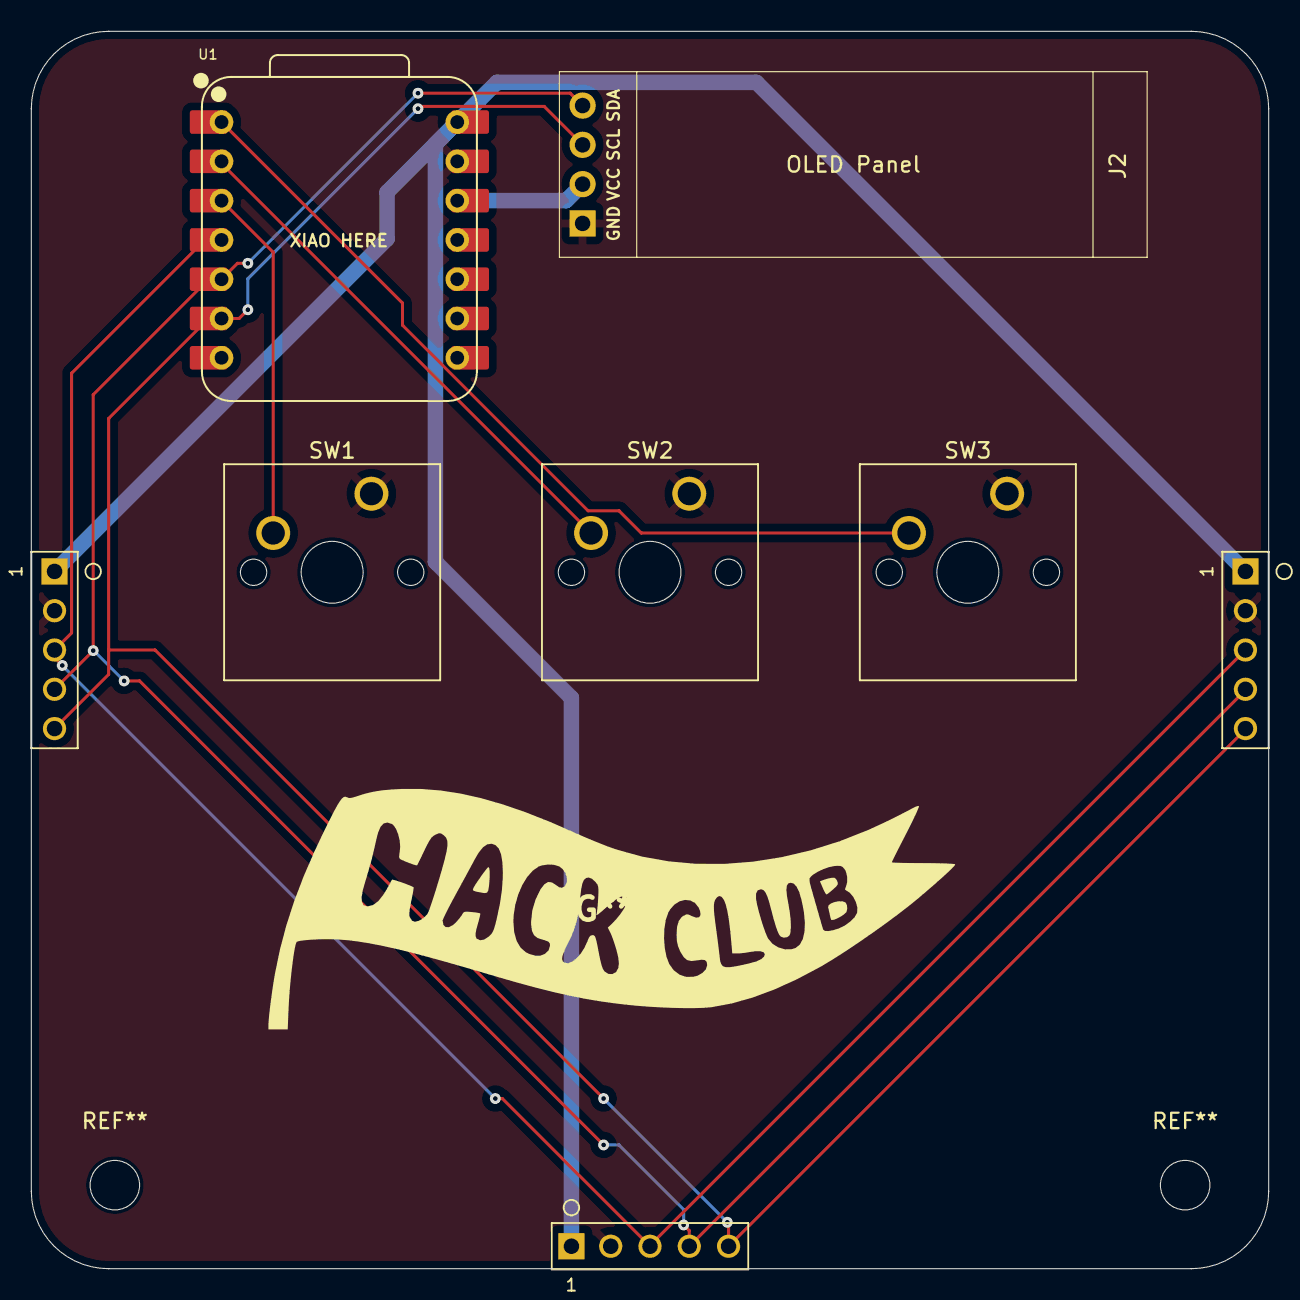
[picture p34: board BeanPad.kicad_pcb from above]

Board: 2 copper layers, 80.0 x 80.0 mm, 8 parts (0 on the bottom side), 9 nets.

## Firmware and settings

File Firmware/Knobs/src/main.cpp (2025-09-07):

#include <Arduino.h>
#include <Wire.h>
#include <ezButton.h>
//1st rotary encoder
#define CLK_PIN_1 D7
#define DT_PIN_1 D8
#define SW_PIN_1 D9
//2nd rotary encoder
#define CLK_PIN_2 D10
#define DT_PIN_2 D1
#define SW_PIN_2 D2
//Directions
#define DIRECTION_CW 0   // clockwise direction
#define DIRECTION_CCW 1  // counter-clockwise direction
// i2c module
#define I2C_ADDRESS 0x20 // I2C address for the module
#define INT_PIN D3 // Interrupt pin for the 1st rotary encoder
//keymap
#define MAX_KEYS 6
uint8_t keymap[MAX_KEYS];
uint8_t keymap_size = 0;
bool keymap_received = false;

int direction = DIRECTION_CW;
int direction_2 = DIRECTION_CW;
int CLK_1_state;
int CLK_2_state;
int prev_CLK_1_state;
int prev_CLK_2_state;

ezButton Rot_Encoder_1(SW_PIN_1);
ezButton Rot_Encoder_2(SW_PIN_2);
int Active_key = 0;
bool action_available = false;
// put function declarations here:
void receiveKeymap(int bytes);
void sendAction(int key);
void requestHandler();
void setup() {
  Wire.begin(I2C_ADDRESS);
  Serial.begin(9600);
  // Interrupt pin
  pinMode(INT_PIN, OUTPUT);
  // configure encoder pins as inputs
  pinMode(CLK_PIN_1, INPUT_PULLUP);
  pinMode(DT_PIN_1, INPUT_PULLUP);
  pinMode(CLK_PIN_2, INPUT_PULLUP);
  pinMode(DT_PIN_2, INPUT_PULLUP);
  Rot_Encoder_1.setDebounceTime(50);
  Rot_Encoder_2.setDebounceTime(50);

  // read the initial state of the rotary encoder's CLK pin
  prev_CLK_1_state = digitalRead(CLK_PIN_1);
  prev_CLK_2_state = digitalRead(CLK_PIN_2);
  // Request keymap
  digitalWrite(INT_PIN, LOW); // Pull the INT pin down indicating a request or action
  Wire.onReceive(receiveKeymap);
  Wire.onRequest(requestHandler);

}

void loop() {
  Rot_Encoder_1.loop();
  Rot_Encoder_2.loop();

  // read the current state of the rotary encoder's CLK pin
  CLK_1_state = digitalRead(CLK_PIN_1);
  CLK_2_state = digitalRead(CLK_PIN_2);
  
  // If CLK was changed, then pulse occurred
  // React to only the rising edge to stop double counting
  //1st rotary encoder
  if (CLK_1_state != prev_CLK_1_state && CLK_1_state == HIGH) {
    if (digitalRead(DT_PIN_1) == HIGH) {
      direction = DIRECTION_CCW;
      sendAction(keymap[1]); // Send action for the 2nd key
    } else {
      direction = DIRECTION_CW;
      sendAction(keymap[0]); // Send action for the 1st key
    }
    //TODO: Rotating broken
    Serial.print("DIRECTION: ");
    if (direction == DIRECTION_CW)
      Serial.print("Clockwise");
    else
      Serial.print("Counter-clockwise");
  }
  prev_CLK_1_state = CLK_1_state;
  //2nd rotary encoder
  if (CLK_2_state != prev_CLK_2_state && CLK_2_state == HIGH) {
    if (digitalRead(DT_PIN_2) == HIGH) {
      sendAction(keymap[4]); // Send action for the 5th key
      direction_2 = DIRECTION_CCW;
    } else {
      direction_2 = DIRECTION_CW;
      sendAction(keymap[3]); // Send action for the 4th key
    }

    Serial.print("DIRECTION: ");
    if (direction_2 == DIRECTION_CW)
      Serial.print("Clockwise");
    else
      Serial.print("Counter-clockwise");
  }
  // save last CLK state
  prev_CLK_2_state = CLK_2_state;
  

  if (Rot_Encoder_1.isPressed()) {
    sendAction(keymap[2]); // Send action for the 3rd key
  }
  if (Rot_Encoder_2.isPressed()) {
    sendAction(keymap[5]); // Send action for the 6th key
  }
}
// put function definitions here:
void receiveKeymap(int bytes) {
  Serial.print("Received ");
  Serial.print(bytes);
  Serial.println(" bytes");
  
  keymap_size = 0;
  
  // Read all incoming bytes as keymap
  while (Wire.available() && keymap_size < MAX_KEYS) {
    keymap[keymap_size] = Wire.read();
    Serial.print("Keymap[");
    Serial.print(keymap_size);
    Serial.print("] = ");
    Serial.println(keymap[keymap_size]);
    keymap_size++;
  }
  digitalWrite(INT_PIN, HIGH);
  // Clear any remaining bytes
  while (Wire.available()) {
    Wire.read();
  }
  
  keymap_received = true;
  Serial.print("Keymap received with ");
  Serial.print(keymap_size);
  Serial.println(" keys");
}
void requestHandler() {
  if (action_available) {
    Wire.write(Active_key); // Send the action
    action_available = false; // Clear flag after sending
    digitalWrite(INT_PIN, HIGH); // Reset INT pin
  } else {
    Wire.write(0); // No action
  }
}
void sendAction(int key) {
  // Send the action corresponding to the key
  Serial.print("Sending action for key: ");
  Serial.println(keymap[key]);
  Active_key = key;
  action_available = true; // Set flag to indicate new action
  digitalWrite(INT_PIN, LOW); // Signal to master
}

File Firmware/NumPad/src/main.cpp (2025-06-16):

#include <Arduino.h>
#include <Wire.h>

// Button matrix configuration
#define ROWS 4
#define COLS 3
#define MAX_KEYS 12

// Define row and column pins
uint8_t rowPins[ROWS] = {3,4,2,1}; // Row pins
uint8_t colPins[COLS] = {26,27,28};    // Column pins

// i2c module
#define I2C_ADDRESS 0x21 // I2C address for the module
#define INT_PIN 29 // Interrupt pin

//keymap
uint8_t keymap[MAX_KEYS];
uint8_t keymap_size = 0;
bool keymap_received = false;

// Button state tracking for matrix
bool currentState[ROWS][COLS];
bool previousState[ROWS][COLS];
unsigned long lastDebounceTime[ROWS][COLS];
unsigned long debounceDelay = 10; // 10ms debounce

// Current key event to send
uint8_t current_key_pressed = 0;
uint8_t key_state = 0; // 0 = released, 1 = pressed

// Function declarations
void receiveEvent(int bytes);
void requestEvent();
void scanMatrix();
void sendAction(uint8_t keyIndex, bool isPressed);

void setup() {
  Wire.begin(I2C_ADDRESS);
  Serial.begin(9600);
  
  // Initialize matrix pins
  for (int i = 0; i < ROWS; i++) {
    pinMode(rowPins[i], OUTPUT);
    digitalWrite(rowPins[i], HIGH); // Set rows HIGH initially
  }
  
  for (int i = 0; i < COLS; i++) {
    pinMode(colPins[i], INPUT_PULLUP); // Columns as inputs with pullup
  }
  
  // Initialize button states
  for (int r = 0; r < ROWS; r++) {
    for (int c = 0; c < COLS; c++) {
      currentState[r][c] = HIGH; // Not pressed (pullup)
      previousState[r][c] = HIGH;
      lastDebounceTime[r][c] = 0;
    }
  }
  
  // Interrupt pin
  pinMode(INT_PIN, OUTPUT);
  digitalWrite(INT_PIN, LOW); // Start Low
  
  // Register I2C event handlers
  Wire.onReceive(receiveEvent);  // When master sends keymap
  Wire.onRequest(requestEvent);  // When master requests key events
  
  Serial.println("NumPad Matrix Ready");
}

void loop() {
  scanMatrix();
}

void scanMatrix() {
  for (int row = 0; row < ROWS; row++) {
    // Set current row LOW
    digitalWrite(rowPins[row], LOW);
    
    
    // Read all columns for this row
    for (int col = 0; col < COLS; col++) {
      bool reading = digitalRead(colPins[col]);
      
      // Check if state changed
      if (reading != previousState[row][col]) {
        lastDebounceTime[row][col] = millis();
      }
      
      // If enough time has passed, update the state
      if ((millis() - lastDebounceTime[row][col]) > debounceDelay) {
        if (reading != currentState[row][col]) {
          currentState[row][col] = reading;
          
          // Calculate key index (0-11 for 4x3 matrix)
          uint8_t keyIndex = (row * COLS) + col;
          
          if (reading == LOW) { // Button pressed (pulled LOW)
            sendAction(keyIndex, true);
          } else { // Button released
            sendAction(keyIndex, false);
          }
        }
      }
      
      previousState[row][col] = reading;
    }
    
    // Set current row back to HIGH
    digitalWrite(rowPins[row], HIGH);
  }
}

void sendAction(uint8_t keyIndex, bool isPressed) {
  if (!keymap_received || keyIndex >= keymap_size) {
    Serial.println("Invalid key index or keymap not received");
    return;
  }
  
  current_key_pressed = keymap[keyIndex];
  key_state = isPressed ? 1 : 0;
  
  // Signal interrupt to master
  digitalWrite(INT_PIN, LOW);
  
  Serial.print("Key ");
  Serial.print(isPressed ? "pressed" : "released");
  Serial.print(": index ");
  Serial.print(keyIndex);
  Serial.print(", action code ");
  Serial.println(current_key_pressed);
}

// Handle receiving keymap from master
void receiveEvent(int bytes) {
  Serial.print("Received ");
  Serial.print(bytes);
  Serial.println(" bytes");
  
  keymap_size = 0;
  
  // Read all incoming bytes as keymap
  while (Wire.available() && keymap_size < MAX_KEYS) {
    keymap[keymap_size] = Wire.read();
    Serial.print("Keymap[");
    Serial.print(keymap_size);
    Serial.print("] = ");
    Serial.println(keymap[keymap_size]);
    keymap_size++;
  }
  
  // Clear any remaining bytes
  while (Wire.available()) {
    Wire.read();
  }
  
  keymap_received = true;
  Serial.print("Keymap received with ");
  Serial.print(keymap_size);
  Serial.println(" keys");
  
  // Release interrupt pin
  digitalWrite(INT_PIN, HIGH);
}

// Handle master requesting key events
void requestEvent() {
  // Send current key event to master
  Wire.write(current_key_pressed);
  Wire.write(key_state);
  
  // Clear the event after sending and release interrupt
  current_key_pressed = 0;
  key_state = 0;
  digitalWrite(INT_PIN, HIGH); // Release interrupt
}

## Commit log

2025-06-09 PCB V1.0 Schematic
    [BeanPad.kicad_pcb, BeanPad.kicad_sch]
2025-06-10 PCB finished v1
    [BeanPad.kicad_pcb, BeanPad.kicad_sch]
2025-06-10 Case and edit PCB
    [BeanPad.kicad_pcb]
2025-06-11 Case V0.1 done
    [BeanPad Bottom.step, BeanPad Top.step]
2025-06-16 Finished Designing
    [BeanPad - Knobs-Bottom.step, BeanPad - Macro-Bottom.step, BeanPad - Macro-Top.step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]
2025-06-19 Fix Macro Module CAD
    [BeanPad - Macro-Bottom.step, BeanPad - Macro-Top.step, BeanPad - Macro.step]
2025-06-19 Fix PCB and Pictures
    [BeanPad.kicad_pcb, Knobs.kicad_pcb, Macro.kicad_pcb]
2025-09-07 Refactor I2C module handling and update PCB files
    Major refactor of I2C communication between the main board and modules: unified pin naming, improved interrupt and keymap handling, and enhanced display logic in the main firmware. Updated PCB projec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
    [Knobs.kicad_pcb, Macro.kicad_pcb, Num-Pad.kicad_pcb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]
